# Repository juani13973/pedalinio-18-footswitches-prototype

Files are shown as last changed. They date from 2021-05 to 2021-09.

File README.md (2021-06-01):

# pedalinio-18-footswitches-prototype.  

I created this repository to share my experience of creating my prototype of the open source [pedalino mini project](https://github.com/alf45tar/PedalinoMini). I am also sharing in this repository the files I created along the way.
It was a great experience and journey. I think I spent the same amount I would have spent if I bought it in a store but !! I LEARNT A LOT :
- I discovered and learnt to use GitHub
- I discovered what happened in the last 25 years with microcontrollers. I used to program in assembler.. (incredible)
- I learnt somehow to use arduino and visual studio
- I learnt to design in FUSION 360 !! that software is free !! - PCBs and the entire project.
- I did PCBs again and instead of DIY at home, I learnt how to buy them in China. What a change !
- I did my first 3D print ever. I was wondering what 3D printing is really for. I discovered a new world.
- I discovered how cheap things are in AliExpress :) - no more amazon

Here are 3 pics of the end result:
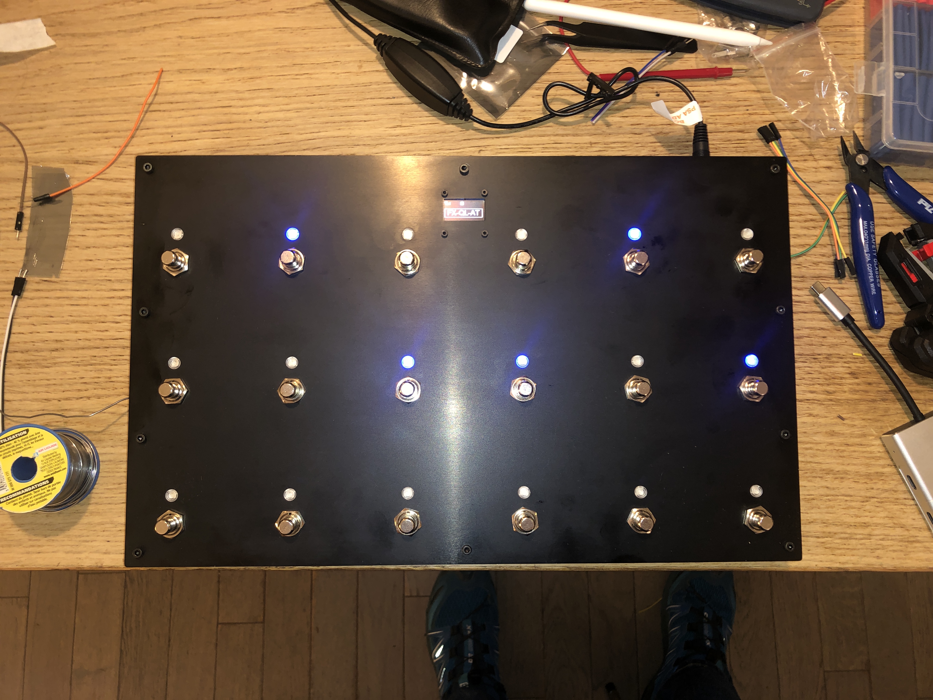
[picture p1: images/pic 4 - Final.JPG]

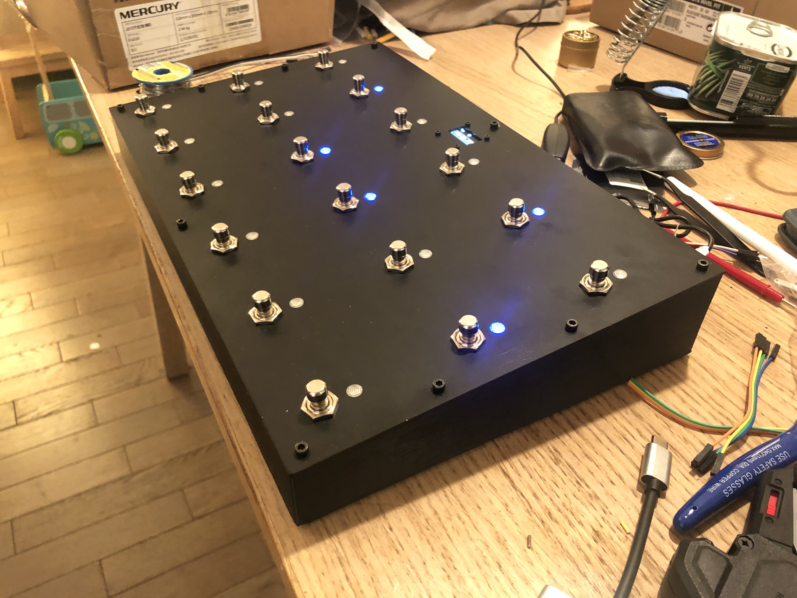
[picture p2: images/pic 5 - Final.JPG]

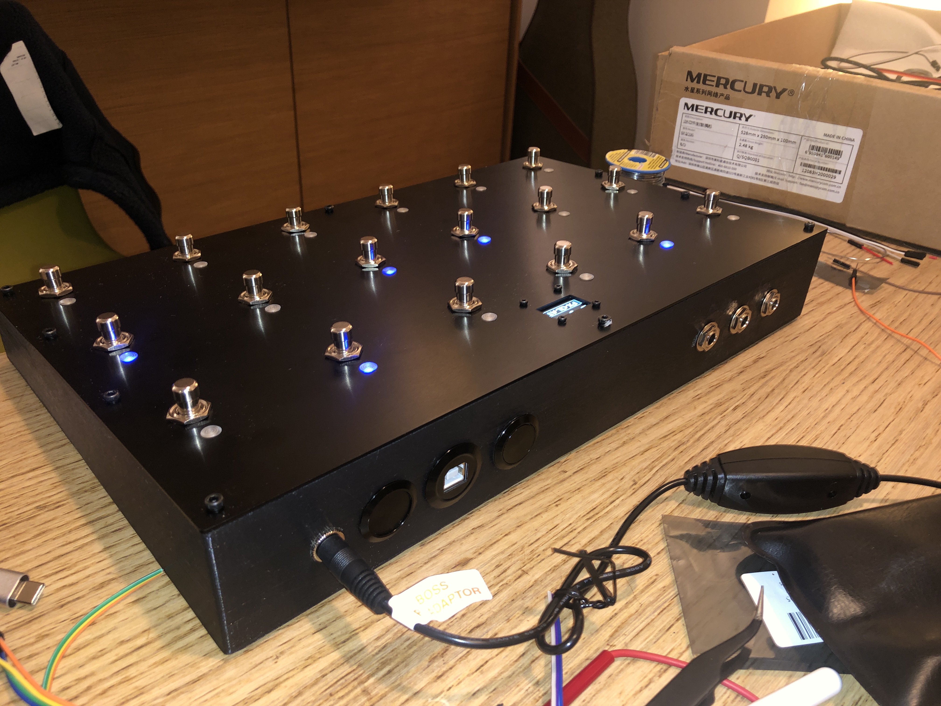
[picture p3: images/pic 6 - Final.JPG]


# My prototype
My prototype has the following features:
- USBMidi interphase that I wanted because my Bluetooth connection used to disconnect on my iPad.
- 18 footswitches leveraging 3 interphases out of the 6 available (6 footswtich ladder configuration)
- 3 external analog interphases leveraging the remaining 3 configuration.
- 18 2812b leds, one for each footswitch.
- LCD display.
- Externalized boot switch to select the profiles A/B/C. For this reason, I am using the 38pin DOIT ESP32 dev board instead of the 30-pins DEV board. (The boot button is in the GPIO-0)
- The mainboard PCB also has pins-out to connect the legacy-midi interphases (circuit to be built in another PCB)

# Fusion 360
Please refer to the [folder Fusion 360](https://github.com/juani13973/pedalinio-18-footswitches-prototype/tree/main/Fusion%20360%20files) to get the files and see how I designed the prototype.
In this section I included some tips on how I thought the construction.

# Creating the prototype
Please refer to the [folder Fusion 360 export files for production](https://github.com/juani13973/pedalinio-18-footswitches-prototype/tree/main/Fusion%20360%20export%20files%20for%20production) to download the files to request the production of the different parts.
In this section I also included some links to some of the components I used.

I hope this information is useful to you and do not hesitate to raise questions for clarification. I will try to answer as soon as I can.
All the best, juani13973

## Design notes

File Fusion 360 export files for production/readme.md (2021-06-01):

In this folder there are several files. All these files are exported from Fusion 360 to produce the final prototype. I sent all these files to [PCBWay](https://www.pcbway.com) and a week later I had at home the final product.
It was incredible to see this happening. 

PCBWay created my PCBs, the 3D printing for the main body and the cover (sheet metal fabrication). The only thing that was not really affordable is the 3D printing.
The price was 280 dollars + shipping cost + customs. The main body should have been a sheet metal prototype as well.  

The cost of the cover that holds the 18 footswitches was 100 dollars (if I order 1 or 3). I ended up ordering 3.  

The cost of the PCBs was very cheap.

#### So the files are:
- ***Cuerpo.stl*** : It is the file of the mainbody to order the 3D print. (exported from Fusion 360)
- ***Placa Pedales V2 horizontal.step*** : It is the file to order the sheet metal with the holes for the leds, footswtiches and LCD. (exported from Fusion 360)
- ***Placa Pedales Drawing.jpg*** : picture I added with the dimensions to order the sheet metal.
- ***Footswtich board - 3 v14_2021-04-13.zip*** : File to order the PCB for the switches. (exported from Fusion 360). You can order directly [here](https://www.pcbway.com/project/shareproject/Footswtich_PCB_for_my_pedalino_mini_prototype.html)
- ***Mainboard_sch_36_revised v18_2021-04-15.zip*** : File to order the mainboard PCB that host the ESP32. (exported from Fusion 360). You can order direclty [here](https://www.pcbway.com/project/shareproject/Pedalino_mini_mainboard.html)

Besides the key components presented in the Pedalino Mini project. I wanted to share some of the prototype :

The [lens](https://www.tme.eu/fr/details/fix-lc5-3/lentilles/fix-fasten/) are small plastic inserts for the finish of the cover.  
You need extra [M12](https://www.ebay.fr/itm/233320916727?hash=item365302a6f7:g:1WQAAOSwXepcTurq) to hold the PCB to the footswitches.  
The [leds](https://www.banggood.com/fr/10Pcs-One-Bit-WS2812B-Serial-5050-Full-Color-LED-Sensor-Module-p-964189.html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). It would be ideal to just by the leds and capacitor without the extra PCB and pins but I couldn't really solder that.  
These are are some of the components I used in the rear pannel:
- [Switch1](https://fr.aliexpress.com/item/1349203593.html?spm=a2g0s.9042311.0.0.46d66c37LY1Li4).  
- [Switch2](https://fr.aliexpress.com/item/1346271859.html?spm=a2g0s.9042311.0.0.39186c37tSKdOL).  
- [USBconnector](https://fr.aliexpress.com/item/1346271859.html?spm=a2g0s.9042311.0.0.46d66c37LY1Li4).  
- [Vin](https://fr.aliexpress.com/item/32974835401.html?spm=a2g0s.9042311.0.0.46d66c37LY1Li4).  
- 6,5mm jacks are standard.  
- These are the [footswitches SPDT](https://fr.aliexpress.com/item/32873378875.html?spm=a2g0s.9042311.0.0.46d66c37LY1Li4).  
- I wouldn't recommend the calbles I used but [these ones](https://fr.aliexpress.com/item/32954418743.html) recommended by @Miqviq.  
- [Inserts](https://www.amazon.fr/gp/product/B08K1BVGN9/ref=ppx_yo_dt_b_asin_title_o02_s00?ie=UTF8&psc=1) for the bolts.  

Here are some pics of to give you an idea:
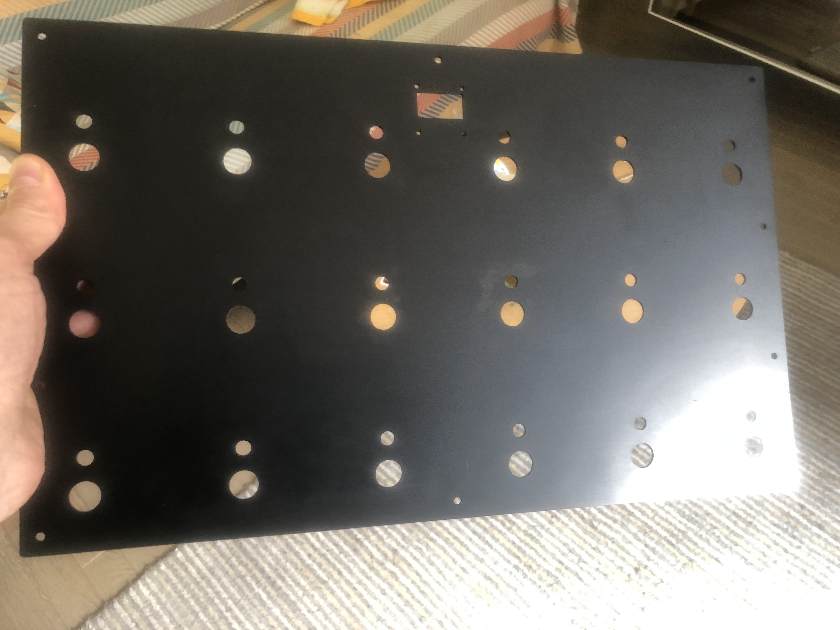
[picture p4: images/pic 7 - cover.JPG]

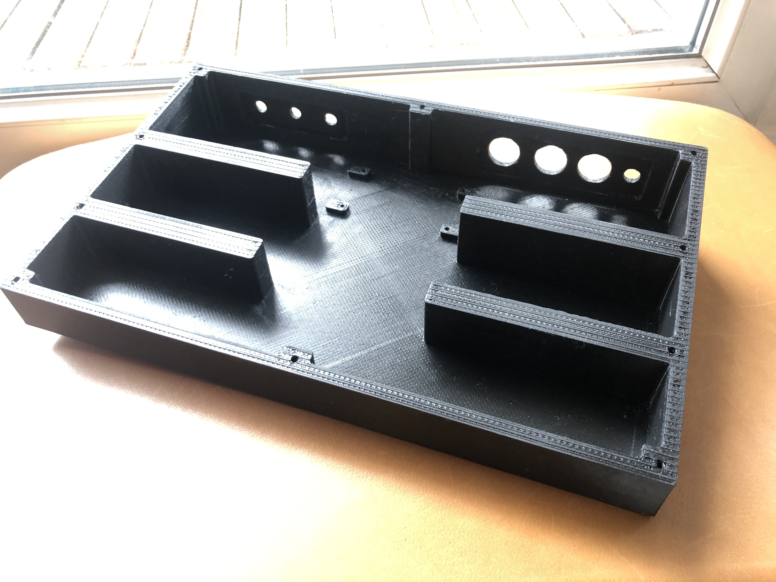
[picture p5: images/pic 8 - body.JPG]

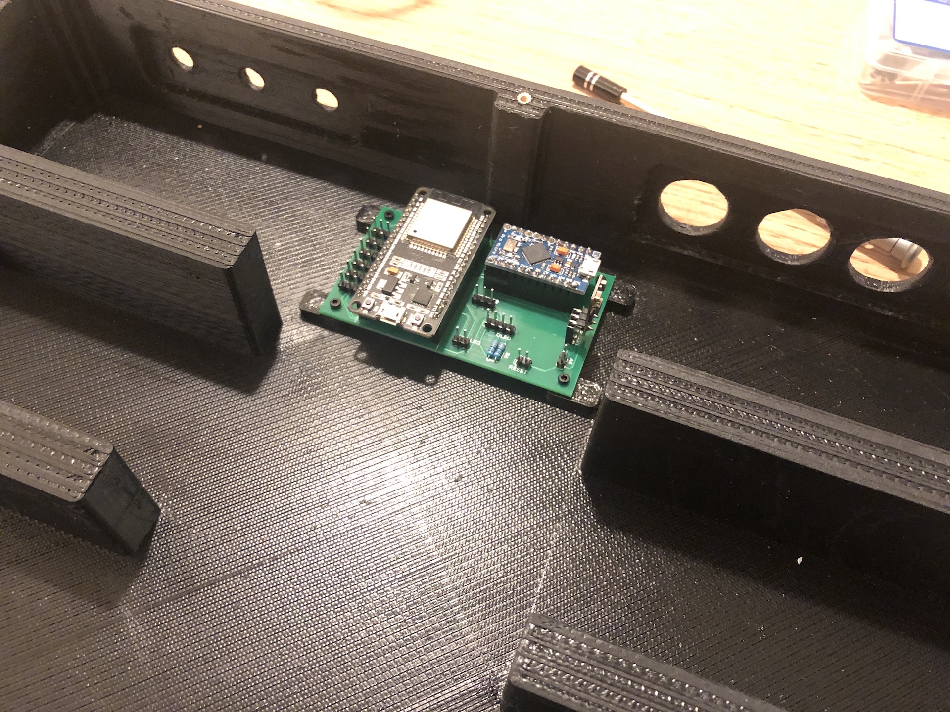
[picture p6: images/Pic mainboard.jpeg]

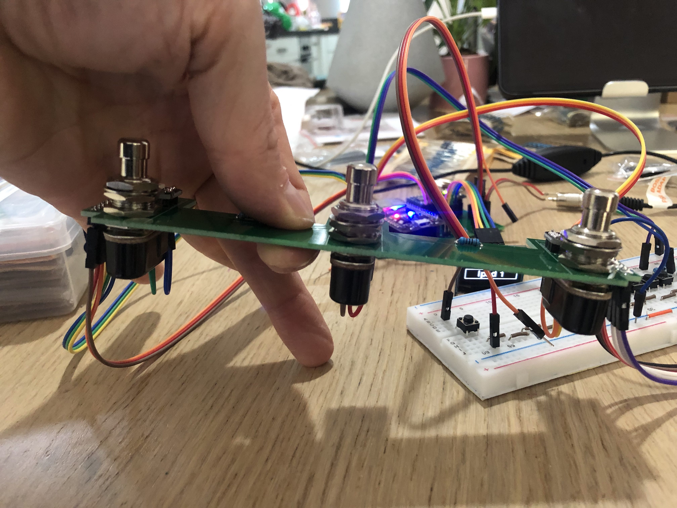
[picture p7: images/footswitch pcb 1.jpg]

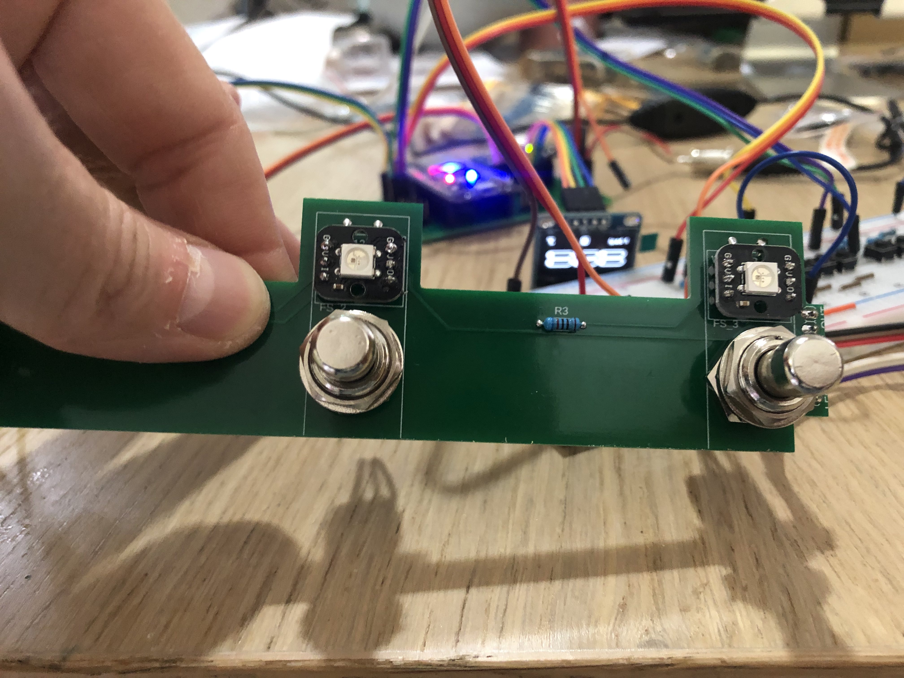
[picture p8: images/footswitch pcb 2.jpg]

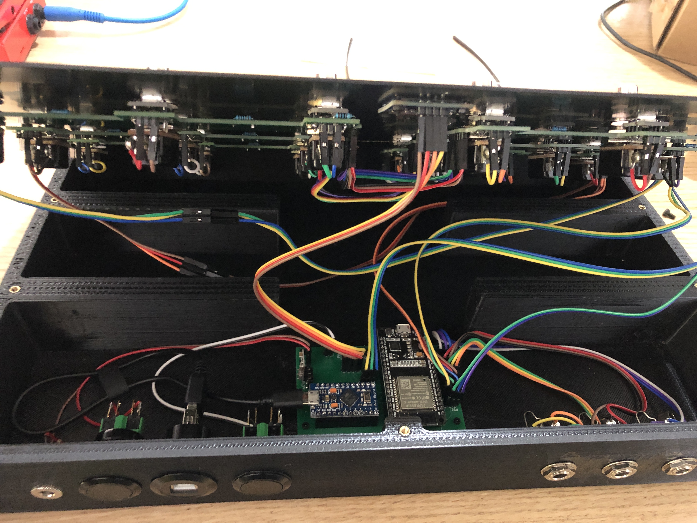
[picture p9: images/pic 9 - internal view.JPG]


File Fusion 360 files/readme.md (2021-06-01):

In this folder there are 3 files that I exported from Fusion 360. I do not know if they can be imported into your fusion 360 app really. But I also have public links for my project.

***Pedalino Mini 2 v23.f3z*** is the main project that has several components:
1. Main body
2. The cover that will hold the 18 switches and the LCD
3. The Mainboard
4. 6 PCB to host 3 footswtiched per PCB. (Since I am using the freeversion of Fusion 360, I was limited in the size of the PCB. I could not host 6 SPDT switches). Those PCBs also have the leds.
5. Finally 18 lens for the leds.

This project is shared by Fusion 360 at : https://a360.co/2SHt98n

***Mainboard v21.f3z*** is the mainboard PCB where the ESP32 is hosted.  
This project is shared by Fusion 360 at : https://a360.co/3iaKelB  
The PCB export is also shared at PCBway. You can order directly the PCBs : https://www.pcbway.com/project/shareproject/Pedalino_mini_mainboard.html

***Footswitch board - 3 v11.f3z*** is the PCB to host 3 SPDT switched and 3 leds. With 2 of these PCBs you can create a ladder for 6 footswitched connected by cables.  
This project is shared by Fusion 360 at : https://a360.co/34yC4eN  
The PCB export is also shared at PCBway. You can order directly the PCBs : https://www.pcbway.com/project/shareproject/Footswtich_PCB_for_my_pedalino_mini_prototype.html  

These are screenshoots of Fusion 360 to give you un idea of the construction:
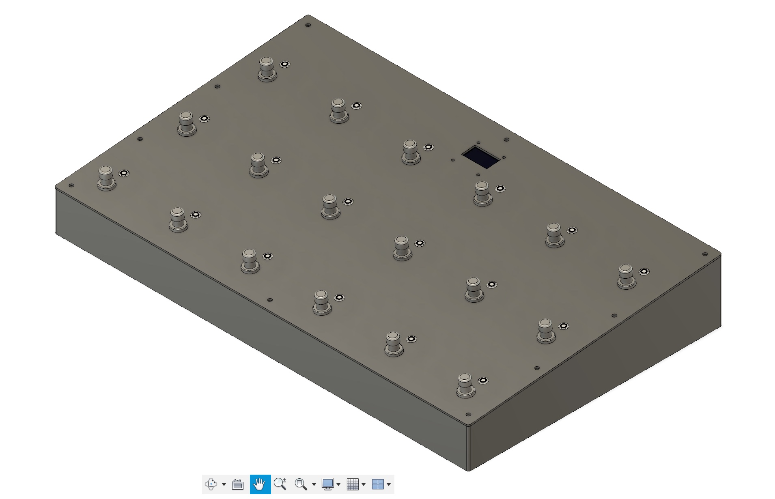
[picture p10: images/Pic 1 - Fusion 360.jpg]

Same view without the sheet metal cover where the 18 footswitches, 18 lends and LCS are hosted. 
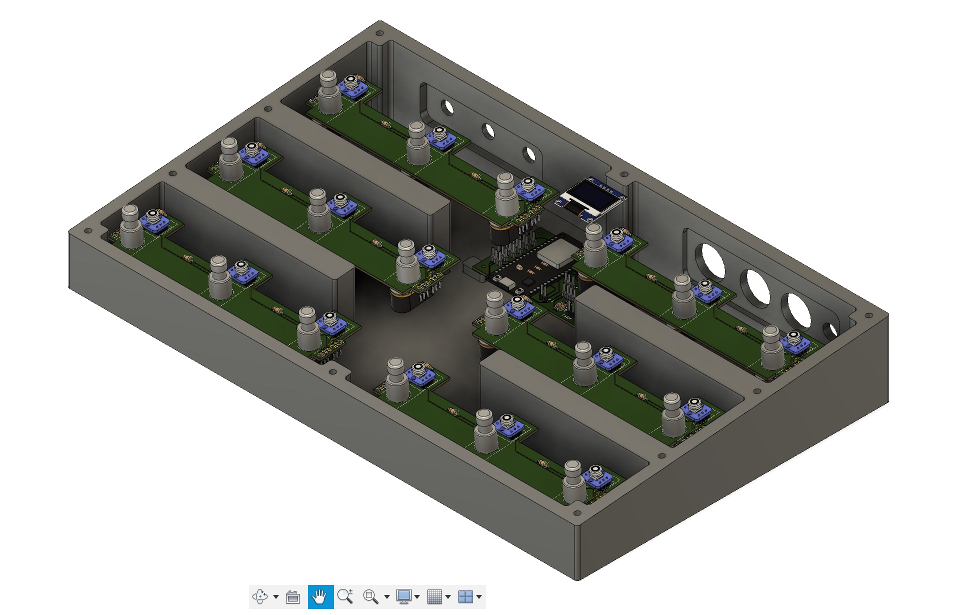
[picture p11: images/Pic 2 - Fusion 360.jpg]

The design of the PCB that host the footswitches and help to build the ladder. You need 2 to build the line of 6 footswitches.
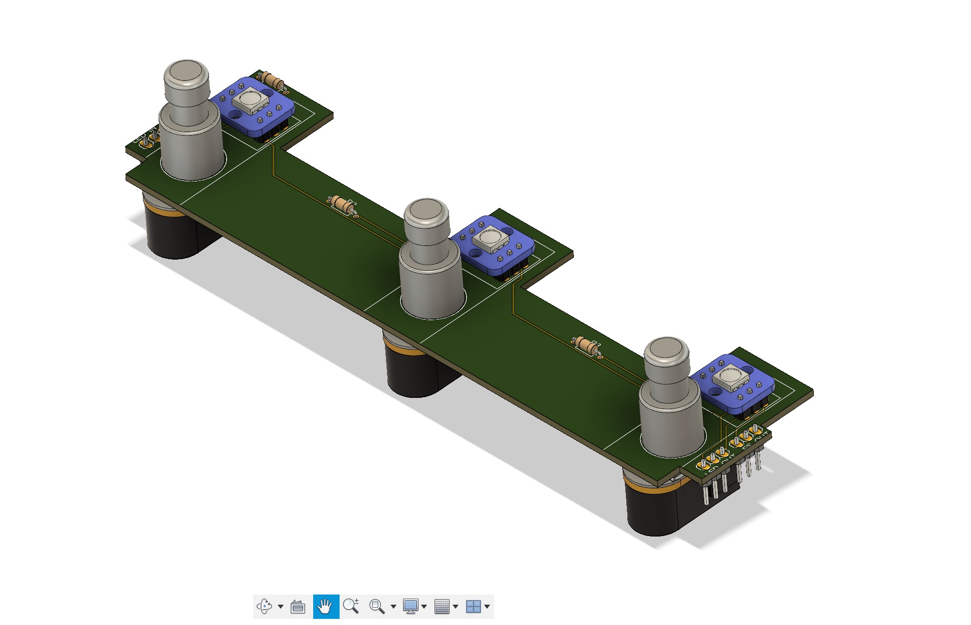
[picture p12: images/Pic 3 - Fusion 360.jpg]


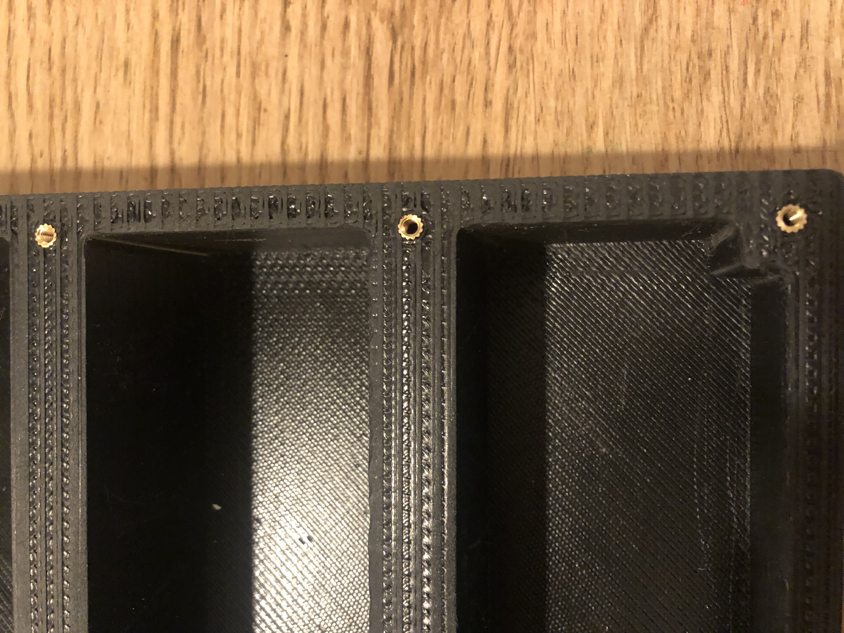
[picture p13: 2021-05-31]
images/Pic 8.5 - inserts.JPG

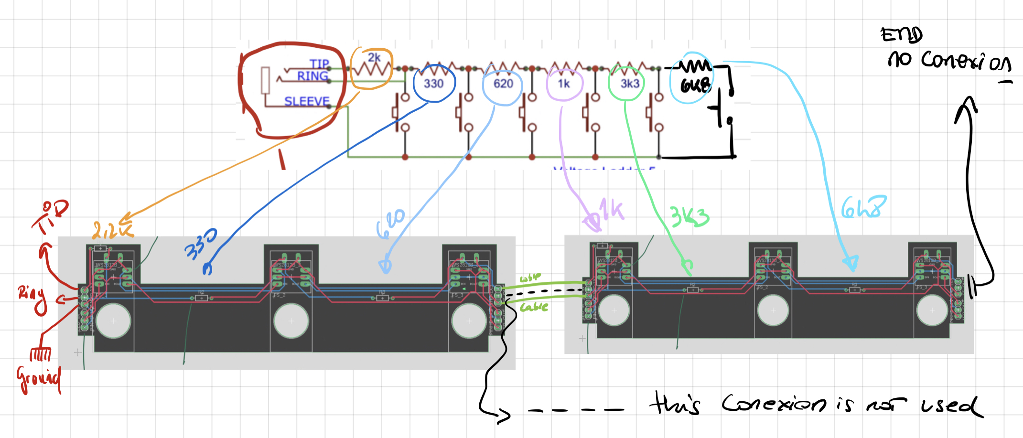
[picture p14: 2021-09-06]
images/Diagram of ladder and PCB.jpeg

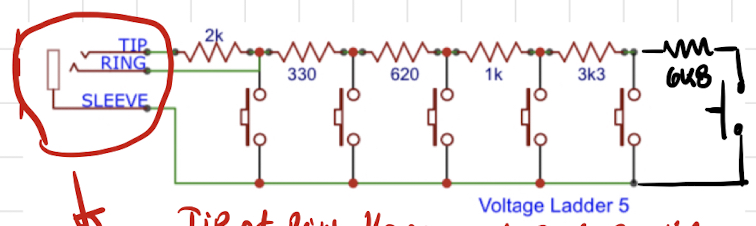
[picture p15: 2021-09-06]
images/Ladder values.jpg

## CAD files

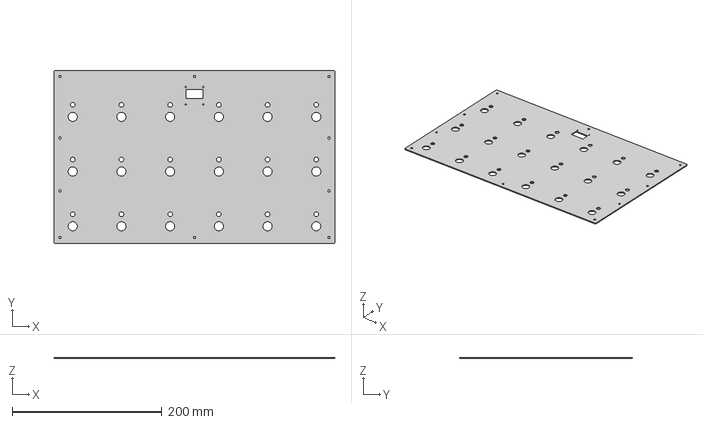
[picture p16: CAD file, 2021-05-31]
Fusion 360 export files for production/Placa Pedales V2 horizontal.step
375.0 x 230.9 x 1.50 mm

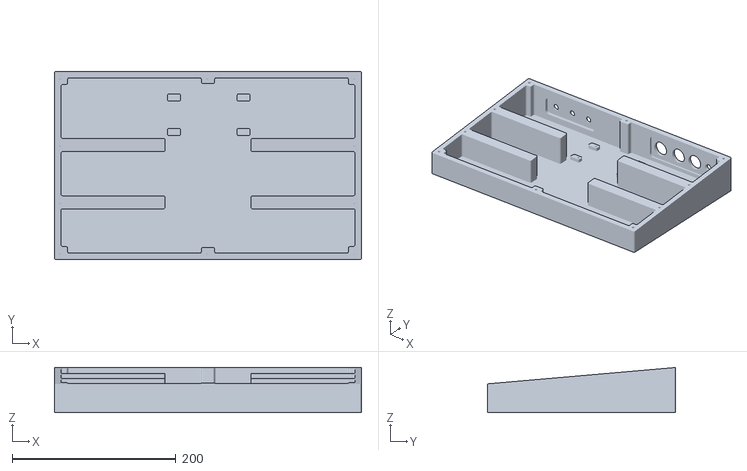
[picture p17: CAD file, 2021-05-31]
Fusion 360 export files for production/Cuerpo.stl
375.0 x 230.0 x 55.0

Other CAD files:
Fusion 360 files/Footswitch board - 3 v11.f3z
Fusion 360 files/Mainboard v21.f3z

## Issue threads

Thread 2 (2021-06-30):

Ordered some PCBs

Sthopeless, 2021-06-30:
Hello there and thanks for sharing your work with us :)

I have ordered a small batch of the Motherboards PCB's and have a few questions if you don't mind

Which Vreg did you use? The pictures can't see very well the pcb

Also I noticed the pins of the Oled don't match my Display, the VCC and GND seem changed, is that correct or your display has it that way?

Last one! only today I noticed the PCB ESP32 has 36 pins, I have ordered one of those from Aliexpress with 38 pins and cannot find one that matches the pinout on the PCB. could you link one of the ESP32 boards for reference?

juani13973, 2021-06-30:
Hi Sthopeless,
what is Vreg ?

This is the [Oled I bought](https://www.banggood.com/fr/3Pcs-0_96-Inch-4Pin-White-IIC-I2C-OLED-Display-Module-12864-LED-p-1154188.html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).

This is the [DOITESP32 dev kit I bought](https://www.banggood.com/fr/ESP32-Development-Board-WiFi+bluetooth-Ultra-Low-Power-Consumption-Dual-Cores-ESP-32-ESP-32S-Board-p-1109512.html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).
Since it has more pins, you can externalise the boot switch and change the A/B/C modes of pedalino externally. You can follow this [link](https://github.com/espressif/esptool/wiki/ESP32-Boot-Mode-Selection) and this [other link](https://www.esp32.com/viewtopic.php?t=5822) to do it.

Sthopeless, 2021-06-30:
thanks alot!!
I've spended all day on Aliexpress searching for the same ESP32 board but couldn't find it..
Lucky all the ones I bought were from Amazon and I can return them!

Once again thanks alot!!

NeidalMcCanuk, 2021-09-21:
Hello and good night. I'm from Mexico and like Sthopeless, I only find in my country the ESP32 with 38 pins (https://articulo.mercadolibre.com.mx/MLM-727796906-esp32-38-pines-esp-wroom-32-_JM), then... if I buy this board, when I load the project (PedalinoMini) in VSCode via PlatformIO, in the "Project Task" tab, should I select the "esp32dev" or "esp32doit-devkit-1" environment?

Another one... PlatformIO is the only way to build and upload the project? or it can be possible via Arduino IDE?

Thanks juani13973!

e36910, 2021-09-30:
Hi, how did you connect led bulbs to esp32? I'm curious about the pinout and how to get them to work on every button press? The interconnection of the button and the LED is necessary, when I press 1 I would like the lamp 1 to turn on, when I press 5 I would like the lamp 5 to turn on and 1 to turn off. Do you know how to solder and configure it?

juani13973, 2021-09-30:
Hi e36910.
Please refer to the project owner to learn about the overall design and project. It is [here](https://github.com/alf45tar/PedalinoMini)

To quickly answer. The leds are not connected to the footswitches. In my design they are in the same PCB but the footswitch ladder and the leds are 2 independent circuits. I put them together so I can mount all easily.

The leds are digital programable leds. They are all connected in serial model. One after the other one and with the software that alf45tar created, you let each one to turn on and off and pick the color you want. So they are not normal cheap leds. They have 16M colors. :)

These leds are [WS2812](https://cdn-shop.adafruit.com/datasheets/WS2812.pdf)

hope this helps,

e36910, 2021-09-30:
Ok, I'll ask you otherwise.  The datа is connected to pin D5, + via vin, and gdn to -.  LEDs one by one.  There are 10 ice and 7 slots in the settings, how did you choose for the 18 ice settings?

juani13973, 2021-10-01:
Hi e36910. I really do not understand your question.

You really need to go into the pedalino mini GitHub repository to find the schematics.

The leds have Vin (+) and GND(-). They are powered with 5V.
Then there is a pin going out of ESP32 into the first Din and after that, you go out on the same led Dout to going in in the 2nd led Din. The ESP32 pin is IO5 (the fiscal PIN number will vary on which board you use).

If you buy the stand alone LEDs you need to add capacitors so you are better if you look for boards already built like the one I used. Or stand alone leds. Follow the schematics of the PDF file.

You need to let the software know how many leds you have. (Again you find this in the QnA of the pedalino project).

Hope this helps,
Juan,

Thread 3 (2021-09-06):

Question about resistors.

NeidalMcCanuk, 2021-09-06:
Hello and good night!

Hello juanni13973, my name is Daniel, and I'm very impressed about your project, I don't know many about electronic, and your PedalinoMini Prototype is very clear, but, I have some questions that I hope you can solve me, please.

1) The 3 resistors in the footswitchs boards, are they all from 10 KOhms?
2) The 6 resistors in the bottom in the mainboard, are they from 10 KOhms?
3) The resistors R7 and R8, what about they? Are the 10KOhms too?
4) About the footswitch boards. Excuse my ignorance please... I understand that for every FSx from the mainboard, there are 2 footswitch boards to complete the ladder of 6 switches, ok. Can you explain me how to link the 1st to the 2nd footswitchboard? I can't figure.

Thanks in advance!!

juani13973, 2021-09-06:
Hi Daniel,
Thx for contacting me and your comments. Let me answer the questions below :

1. The 3 resistors in the footswitchs boards, are they all from 10 KOhms?
No not at all, they are all different building a resistors ladder of 6 footswiches. If you open the Fusion 360 file you will see the values. Or if you go to the pedalino project, you will see a ladder of 5 footswitches. I added 1 more with a 6K8ohms resistor.

2. The 6 resistors in the bottom in the mainboard, are they from 10 KOhms?
Yes all the ones that are below the ESP32 are all 10K (again, did you download the diagrams from alf45tar ? - took them from the project itself)

3. The resistors R7 and R8, what about they? Are the 10KOhms too?
Nop, they are 3K3 Ohms. (Again look at the diagram in alf45tar page or open my fusion 360 file and you will have them all there).

4. About the footswitch boards. Excuse my ignorance please... I understand that for every FSx from the mainboard, there are 2 footswitch boards to complete the ladder of 6 switches, ok. Can you explain me how to link the 1st to the 2nd footswitchboard? I can't figure.
Correct. I wanted to build one PCB board with 6 foot-switches but I had to pay for a full license of Fusion 360, so I had to split the PCB in 2 parts. Each ladder has 3 + 3 foot-switches in 2 different boards.
Look at this diagram, I hope it is clear…..

Juan,

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

juani13973, 2021-09-06:
Hi Daniel,
Thx for contacting me and your comments. Let me answer the questions below :

1. The 3 resistors in the footswitchs boards, are they all from 10 KOhms?
No not at all, they are all different building a resistors ladder of 6 footswiches. If you open the Fusion 360 file you will see the values. Or if you go to the pedalino project, you will see a ladder of 5 footswitches. I added 1 more with a 6K8ohms resistor. [look at the picture](https://github.com/juani13973/pedalinio-18-footswitches-prototype/blob/main/images/Ladder%20values.jpg)

2. The 6 resistors in the bottom in the mainboard, are they from 10 KOhms?
Yes all the ones that are below the ESP32 are all 10K (again, did you download the diagrams from alf45tar ? - took them from the project itself)

3. The resistors R7 and R8, what about they? Are the 10KOhms too?
Nop, they are 3K3 Ohms. (Again look at the diagram in alf45tar page or open my fusion 360 file and you will have them all there).

4. About the footswitch boards. Excuse my ignorance please... I understand that for every FSx from the mainboard, there are 2 footswitch boards to complete the ladder of 6 switches, ok. Can you explain me how to link the 1st to the 2nd footswitchboard? I can't figure.
Correct. I wanted to build one PCB board with 6 foot-switches but I had to pay for a full license of Fusion 360, so I had to split the PCB in 2 parts. Each ladder has 3 + 3 foot-switches in 2 different boards.
Look at this diagram, I hope it is clear…..

NeidalMcCanuk, 2021-09-06:
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

Good afternoon!

Oh man! Thanks, I say it before... I'm not a electronic, and I can't figure it this so easy, I think that you use the ladder with 6 witches labeled as "T Helicon Switch 6".

I'll download then a visor or program to see the f3z files content to clarify me more.

Thanks man and excuse me!

juani13973, 2021-09-06:
Hi Daniel
No I didn’t use that one.
I use the other one. Look at the diagram… it is not the same

Closed 2021-09-21.

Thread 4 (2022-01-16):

Switches quantity

SpacewormSera, 2022-01-16:
Hi Juani13973! I want to build my version on Pedalino a I want to ask you a question. How did you managed to connect 18 footswitches? Did you use resistor ladder? I want to connect 8 footswitches, what is the schematic of this kind of connection?

juani13973, 2022-01-18:
Hi SpacewormSera,
I used 3 interphases with a 6 footswitch ladder in each. On the other 3 I put an analog input for pedals.
Look at the diagram of the project and for 8 foot switches you do not need a ladder. I would use 4 interphases with the Momentary 2. (much simpler without resistors)

juani13973, 2022-01-20:
Yes, correct. that is what I meant.
there are 6. you will use 4 and you will put 2 foot switches per interphase.
Remember that I just implemented the pedalino mini project. I didn't created the project. I would refer to  alf45tar page. (look at my intro)
Juan,

SpacewormSera, 2022-01-29:
Thank you!
Yeah, I know that is a alf45tar's project, I found you in his page. So yeah, I desided to use ladder and momentary switches because in some cases I need double clicks and long clicks, and in the other cases just single clicks in ladder approach.

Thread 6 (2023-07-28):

Just some how-to-do question

gubi80, 2023-07-28:
Hi Juan,

awesome job and thanks for sharing (also the layouts and stuff). I'd like to build one but ama bit reluctant when it comes to coding.
I'd do 8 switches I guess and some input for expression pedal. On the other hand I'd need to connect legacy MIDI for my fx unit and
amp plus a diy loop switch.
The thing is: did you need to code a lot? I  mean to register the 18 switches and to tell them the MIDI channel, CC or PCh and so on...Or is this just something you configure in a third party software/app? From the original project I cannot really determine what is done so far
so I'd need to estimate if I need to do coding and if my knowledge of code would be sufficient for a project like this....

Thanks for any hints ;-)

juani13973, 2023-07-28:
Hi
I did t have to code at all but :
You need to download the Development platform to compile and upload the SW to the controller.
And even though you do not code you need to set up some parameters in the code based on your config (I recall)
it wasn’t rocket science but I am, well I was ….. an electronic engineer
Good luck

On 28 Jul 2023, at 15:52, gubi80 ***@***.***> wrote:

Hi Juan,

awesome job and thanks for sharing (also the layouts and stuff). I'd like to build one but ama bit reluctant when it comes to coding.
I'd do 8 switches I guess and some input for expression pedal. On the other hand I'd need to connect legacy MIDI for my fx unit and
amp plus a diy loop switch.
The thing is: did you need to code a lot? I mean to register the 18 switches and to tell them the MIDI channel, CC or PCh and so on...Or is this just something you configure in a third party software/app? From the original project I cannot really determine what is done so far
so I'd need to estimate if I need to do coding and if my knowledge of code would be sufficient for a project like this....

Thanks for any hints ;-)

—
Reply to this email directly, view it on GitHub<https://github.com/juani13973/pedalinio-18-footswitches-prototype/issues/6>, or unsubscribe<https://github.com/notifications/unsubscribe-auth/ASSJM2GJ4XHFJWA57RFUKUDXSO7ZDANCNFSM6AAAAAA23RCPTI>.
You are receiving this because you are subscribed to this thread.Message ID: ***@***.***>
